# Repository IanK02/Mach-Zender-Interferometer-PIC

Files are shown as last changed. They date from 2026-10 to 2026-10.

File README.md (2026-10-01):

# Mach-Zender Interferometer Photonic Integrated Circuit

A photonic integrated circuit designed in Python with [gdsfactory](https://github.com/gdsfactory/gdsfactory), laid out in [KLayout](https://www.klayout.de/), with a companion PCB designed in [KiCad](https://www.kicad.org/).

Chip implements four Mach-Zender-Interferometers of varying lengths, with accompanying chip providing all required electrical usage and testing hardware.

## Gallery

| Die Layout | PCB 3D View |
|:---:|:---:|
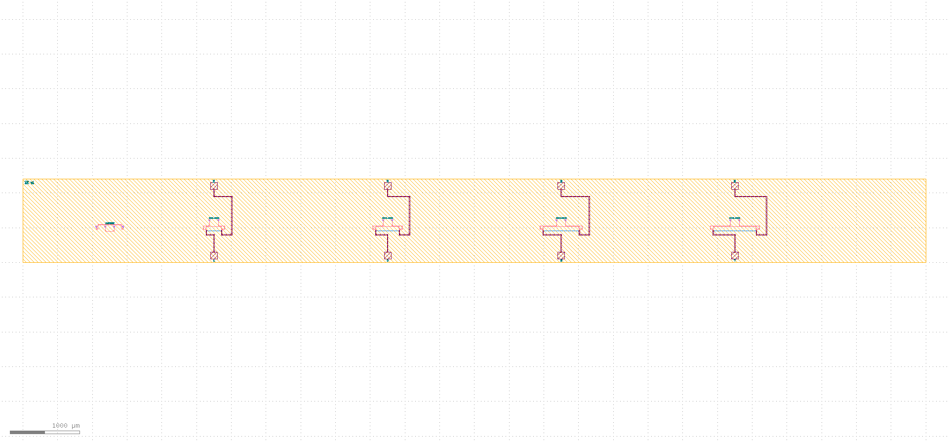
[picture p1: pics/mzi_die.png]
Full die layout
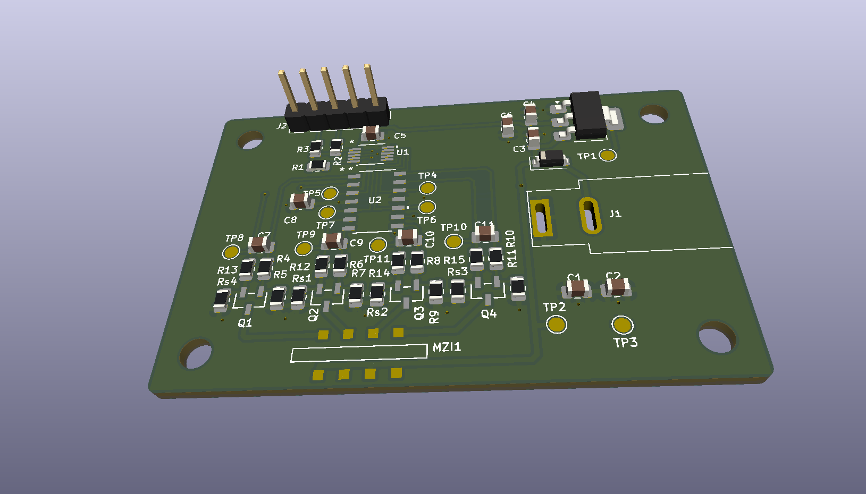
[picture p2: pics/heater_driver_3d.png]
PCB 3D View
|  |  |
| **PCB 2D View** | **Circuit Schematic** |
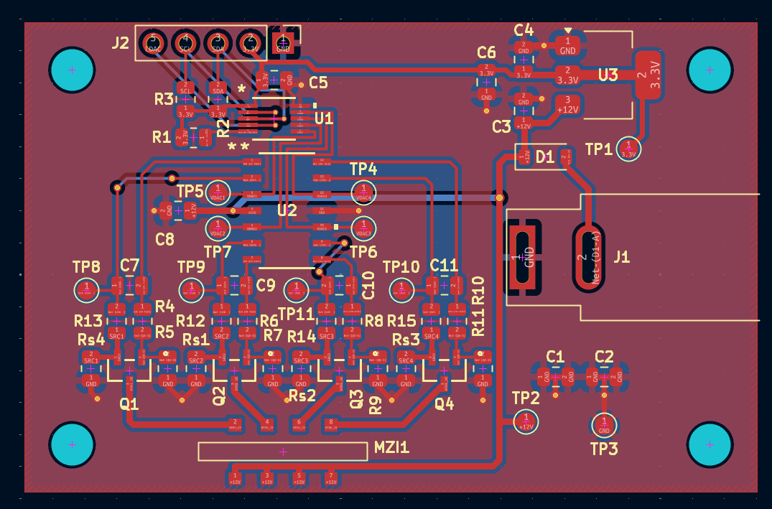
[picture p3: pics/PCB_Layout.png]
PCB 2D Render
|  | Circuit Schematic |

## Features

- Four MZIs with thermal phase shifters
- 12V barrel jack connector for power
- Glue-in spot on PCB for inserting MZI chip

## PDK

This design uses gdsfactory's open-source generic PDK, so the whole layout can be regenerated and freely shared. Layer numbers and components are generic and not tied to any commercial foundry process.

## Tools
- **gdsfactory**: parametric layout in Python
- **KLayout**: layout viewing and rendering
- **KiCad**: schematic and PCB design

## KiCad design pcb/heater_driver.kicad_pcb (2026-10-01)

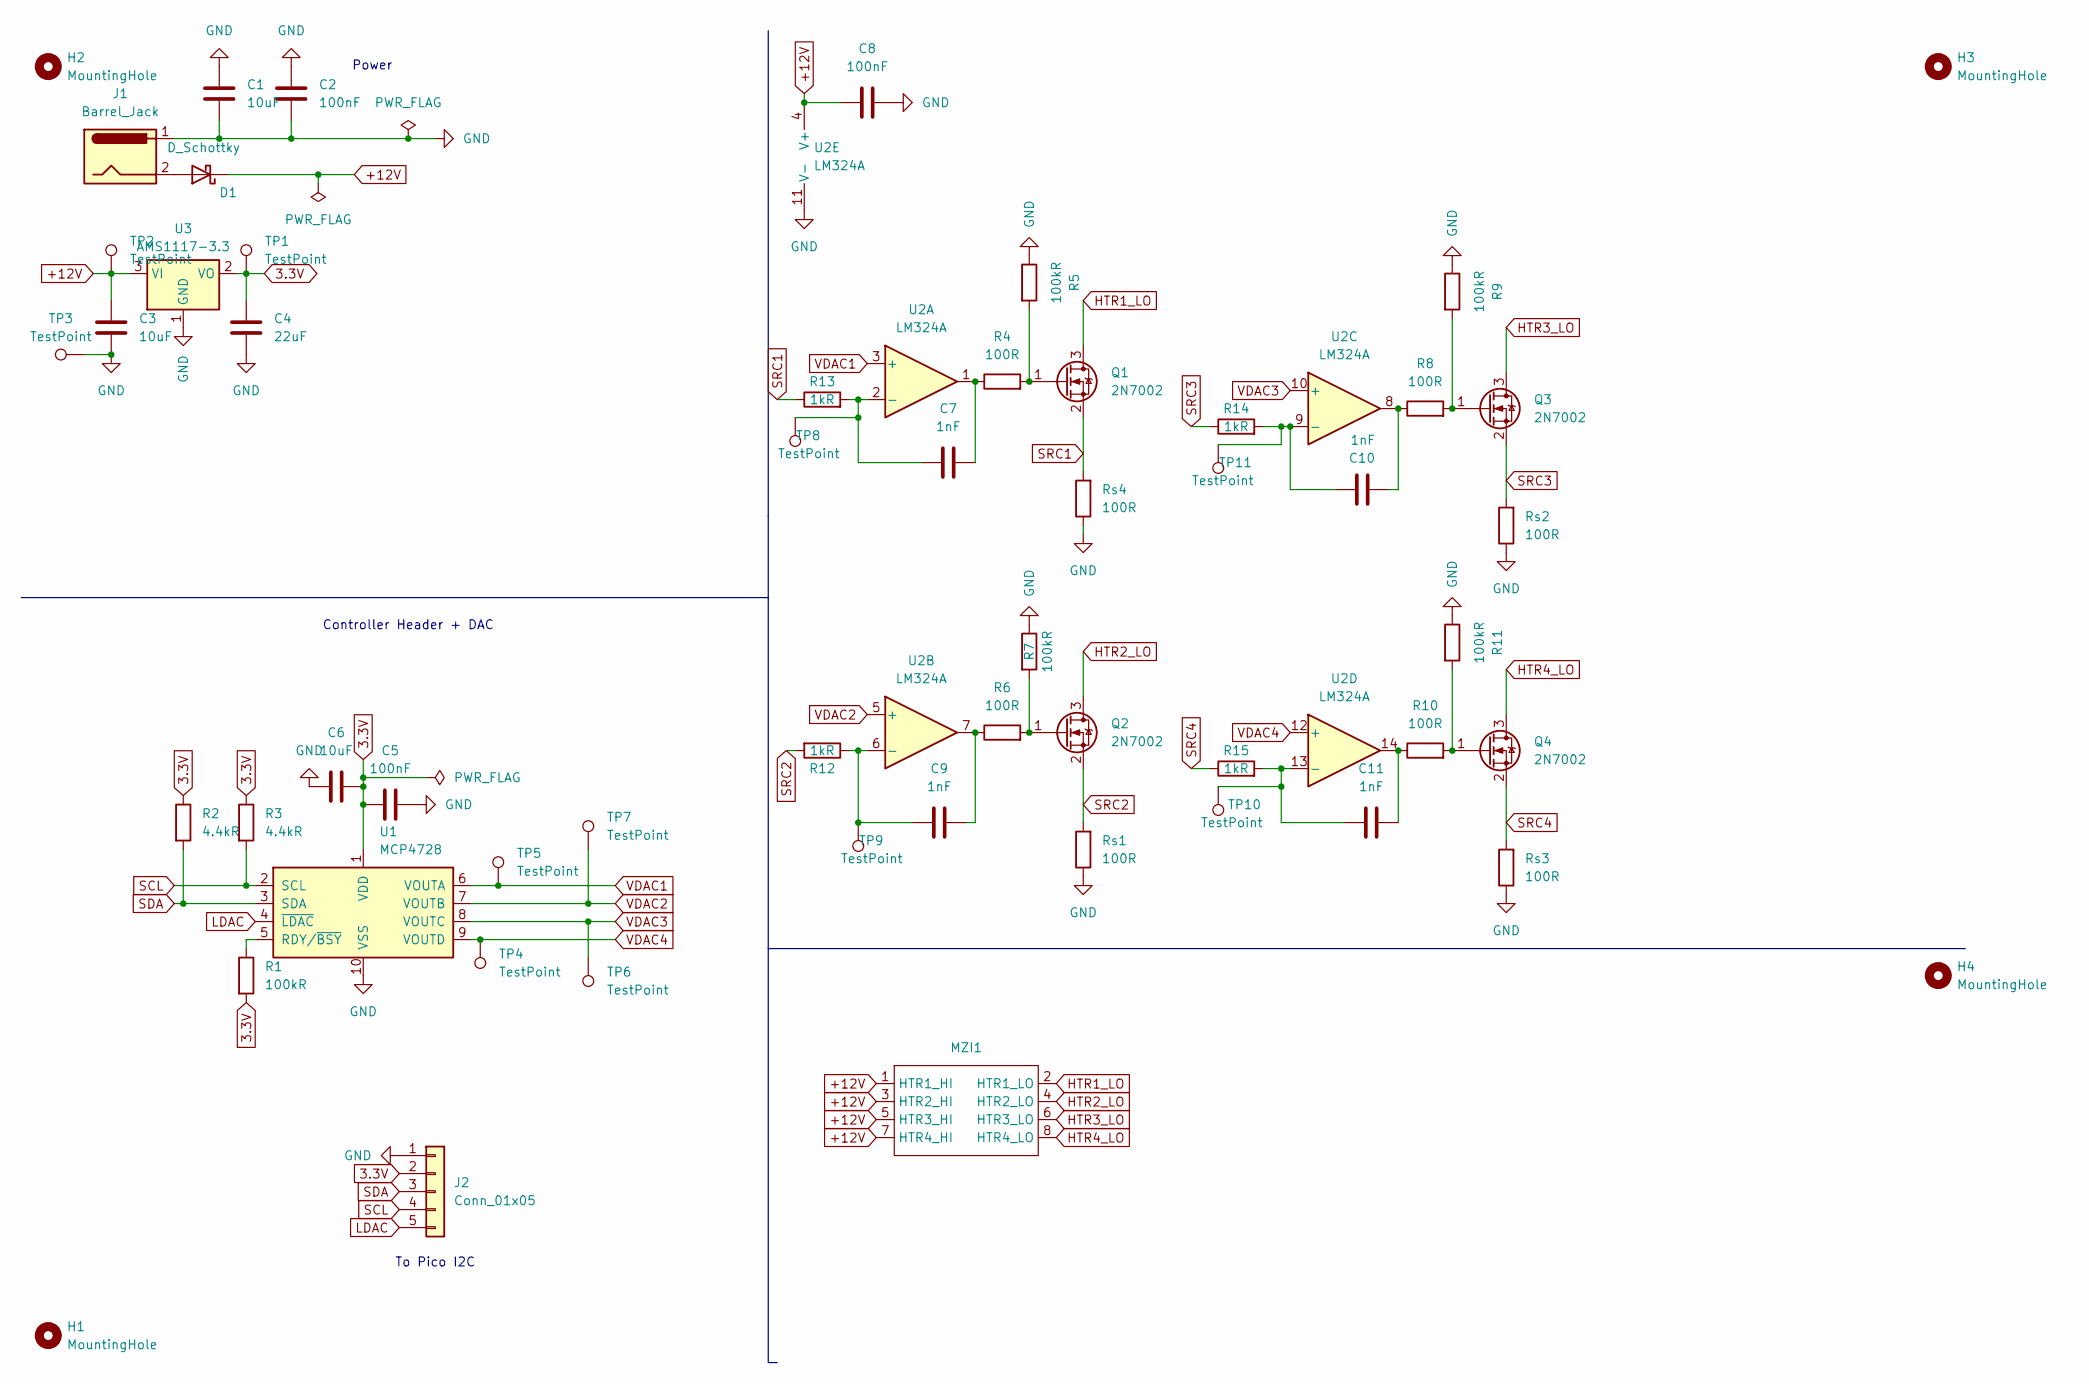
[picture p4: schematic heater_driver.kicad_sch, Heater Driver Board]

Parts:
C1, C3, C6: 10uF; C_0805_2012Metric; MPN GMC04X5R106M10NT; LCSC C1691
C2, C5, C8: 100nF; C_0805_2012Metric; MPN C0603C104K5RACTU; LCSC C1525
C4: 22uF; C_0805_2012Metric; MPN GMC04X5R226M6R3NT; LCSC C1859
C7, C9, C10, C11: 1nF; C_0805_2012Metric; MPN 0805B102K101BD; LCSC C1523
D1: D_Schottky; D_SOD-123; MPN BAT54LT1G; LCSC C82544
H1, H2, H3, H4: MountingHole; MountingHole_3.2mm_M3
J1: Barrel_Jack; BarrelJack_SwitchcraftConxall_RAPC10U_Horizontal; MPN PJ-037A
J2: Conn_01x05; PinHeader_1x05_P2.54mm_Vertical
MZI1: PIC_MZI_DIE
Q1, Q2, Q3, Q4: 2N7002; SOT-23TO-236_318-08_ONS; MPN 2N7002
R1, R5, R7, R9, R11: 100kR; R_0805_2012Metric; MPN CR0603FB100KS1
R2, R3: 4.4kR; R_0805_2012Metric; MPN RN73H1JTTD3442F100
R4, R6, R8, R10: 100R; R_0805_2012Metric; MPN CR0402JC100RS1
R12, R13, R14, R15: 1kR; R_0805_2012Metric; MPN ERJ-2RKF1001X
Rs1, Rs2, Rs3, Rs4: 100R; R_0805_2012Metric; MPN CR0402JC100RS1
TP1, TP2, TP3, TP4, TP5, TP6, TP7, TP8, TP9, TP10, TP11: TestPoint; TestPoint_Pad_D1.5mm; MPN 36-5006-ND
U1: MCP4728; MSOP10_MC_MCH; MPN MCP4728T-E/UN
U2: LM324A; M14A; MPN LM324DR; LCSC C5288549
U3: AMS1117-3.3; SOT-223-3_TabPin2; MPN AMS1117-3.3 SOT-223

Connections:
3.3V: C4.1, C5.1, C6.2, J2.2, R1.2, R2.1, R3.1, TP1.1 (1_1), U1.1 (VDD), U3.2 (VO)
+12V: C3.1, C8.1, D1.1 (K), MZI1.1 (HTR1_HI), MZI1.3 (HTR2_HI), MZI1.5 (HTR3_HI), MZI1.7 (HTR4_HI), TP2.1 (1_1), U2.4 (V+), U3.3 (VI)
GND: C1.1, C1.2, C2.1, C2.2, C3.2, C4.2, C5.2, C6.1, C8.2, J1.1, J2.1, R5.1, R7.1, R9.1, R11.1, Rs1.1, Rs2.1, Rs3.1, Rs4.1, TP3.1 (1_1), U1.10 (VSS), U2.11 (V-), U3.1 (GND)
HTR1_LO: MZI1.2 (HTR1_LO), Q1.3 (D)
HTR2_LO: MZI1.4 (HTR2_LO), Q2.3 (D)
HTR3_LO: MZI1.6 (HTR3_LO), Q3.3 (D)
HTR4_LO: MZI1.8 (HTR4_LO), Q4.3 (D)
LDAC: J2.5, U1.4 (~LDAC)
unnamed: C7.2, R4.1, U2.1
unnamed: C9.2, R6.1, U2.7
unnamed: C10.1, R8.1, U2.8
unnamed: C11.2, R10.1, U2.14
unnamed: D1.2 (A), J1.2
unnamed: Q1.1 (G), R4.2, R5.2
unnamed: Q2.1 (G), R6.2, R7.2
unnamed: Q3.1 (G), R8.2, R9.2
unnamed: Q4.1 (G), R10.2, R11.2
unnamed: R1.1, U1.5 (RDY/~BSY)
unnamed: C7.1, R13.2, TP8.1 (1_1), U2.2 (-)
unnamed: C9.1, R12.1, TP9.1 (1_1), U2.6 (-)
unnamed: C10.2, R14.2, TP11.1 (1_1), U2.9 (-)
unnamed: C11.1, R15.2, TP10.1 (1_1), U2.13 (-)
SCL: J2.4, R3.2, U1.2 (SCL)
SDA: J2.3, R2.2, U1.3 (SDA)
SRC1: Q1.2 (S), R13.1, Rs4.2
SRC2: Q2.2 (S), R12.2, Rs1.2
SRC3: Q3.2 (S), R14.1, Rs2.2
SRC4: Q4.2 (S), R15.1, Rs3.2
VDAC1: TP5.1 (1_1), U1.6 (VOUTA), U2.3 (+)
VDAC2: TP7.1 (1_1), U1.7 (VOUTB), U2.5 (+)
VDAC3: TP6.1 (1_1), U1.8 (VOUTC), U2.10 (+)
VDAC4: TP4.1 (1_1), U1.9 (VOUTD), U2.12 (+)

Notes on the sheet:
Power
Controller Header + DAC
To Pico I2C

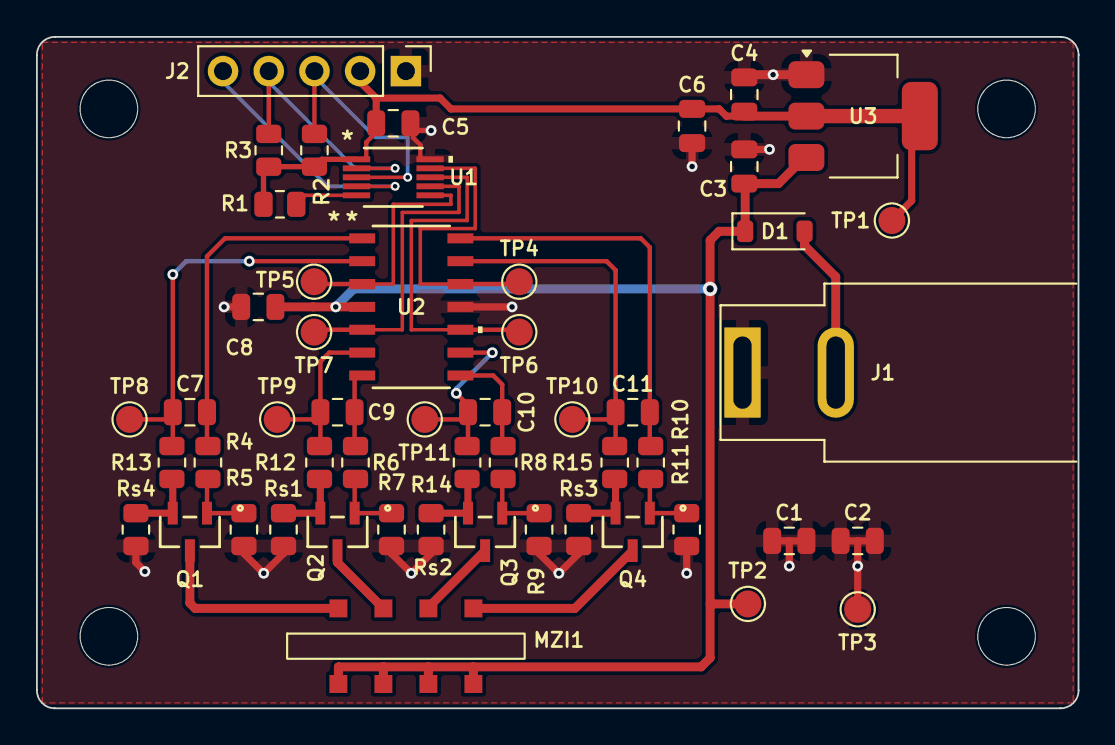
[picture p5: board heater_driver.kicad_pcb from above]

Board: 2 copper layers, 57.9 x 37.3 mm, 56 parts (0 on the bottom side), 32 nets.
